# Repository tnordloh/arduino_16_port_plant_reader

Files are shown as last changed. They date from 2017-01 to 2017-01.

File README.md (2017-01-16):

# Plant moisture sensor, with up to 16 ports #

This moisture sensor uses arduino's analog sensor, to detect when a plant needs
to be watered.  Placing two wires into the plant soil, then sending a charge
through the soil will produce a number between 0 and 1023.  With some
experimentation, we picked "550" as dry, and "650" as REALLY dry.  

The Arduino we're using has only 6 analog ports, so we are extending the 
capabilities, by using two 
[SparkFun Analog/Digital MUX Breakout - CD74HC4067](https://www.sparkfun.com/products/9056).

the MUX (aka multiplexer) uses five ports, but can create access to 16 additional
ports.  We use two of these; one to apply power, the other to read how much 
power gets through.  

Additionally, each of the moisture sensors has an LED built into it, so that we
can light up  which of the 16 plants require watering.  To address the 16 lights, 
we are using two
[SN74HC595 8-Bit shift registers](https://www.sparkfun.com/products/13699), 
which consumes three more ports on the Arduino.

Since we had a couple of ports left over, we wired up a small lcd screen, so that
we can visually verify what each plant is actually registering.  This was 
just for fun, but it could be used to set each individual plant to its own
level of dryness, to make up for differences between each sensor, or differences
in soil, that might make the moisture sensors inaccurate.

Here's what the wiring diagram looks like:
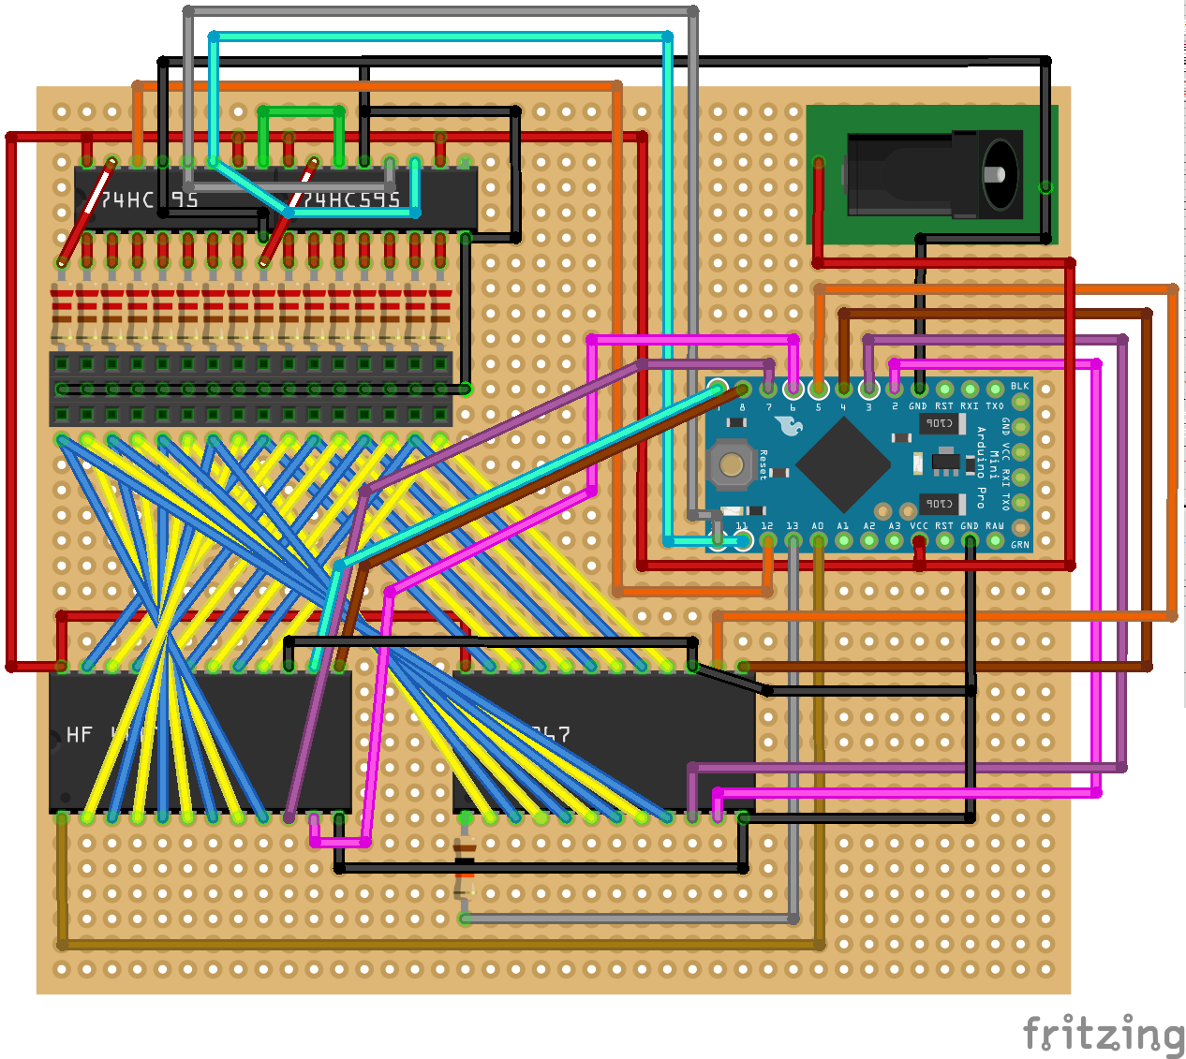
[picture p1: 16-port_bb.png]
fritzing file


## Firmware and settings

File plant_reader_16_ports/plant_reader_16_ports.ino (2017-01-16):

#include <SoftwareSerial.h>

int secondcount = 0;

// Attach the serial display's RX line to digital pin 2
SoftwareSerial mySerialData(A4,13); // RX,TX (unused)

int sensorValue[16] = {0,0,0,0,
                       0,0,0,0,
                       0,0,0,0,
                       0,0,0,0
                     };
int sensorpower = A0;

//Mux control pins
int s0 = 2;
int s1 = 3;
int s2 = 4;
int s3 = 5;

int s4 = 6;
int s5 = 7;
int s6 = 8;
int s7 = 9;
//int muxstate = 6;
//Mux in "SIG" pin
int SIG_pin = A1;


//set up shift register pins
int SER_Pin   = 10; //pin 14 on the 75HC595
int RCLK_Pin  = 11; //pin 12 on the 75HC595
int SRCLK_Pin = 12; //pin 11 on the 75HC595

//Number of daisy-chained shift registers
#define number_of_74hc595s 2 

//do not touch
#define numOfRegisterPins number_of_74hc595s * 8
boolean registers[numOfRegisterPins];

void setup() {

  pinMode(SER_Pin, OUTPUT);
  pinMode(RCLK_Pin, OUTPUT);
  pinMode(SRCLK_Pin, OUTPUT);


  pinMode(SIG_pin, INPUT);
  pinMode(sensorpower, OUTPUT);
  digitalWrite(sensorpower, LOW);

  //set Mux initial values
  pinMode(s0, OUTPUT); 
  pinMode(s1, OUTPUT); 
  pinMode(s2, OUTPUT); 
  pinMode(s3, OUTPUT); 
  pinMode(s4, OUTPUT); 
  pinMode(s5, OUTPUT); 
  pinMode(s6, OUTPUT); 
  pinMode(s7, OUTPUT); 
  //pinMode(muxstate, OUTPUT);

  //initialize mux to C0
  digitalWrite(s0, LOW);
  digitalWrite(s1, LOW);
  digitalWrite(s2, LOW);
  digitalWrite(s3, LOW);
  digitalWrite(s4, LOW);
  digitalWrite(s5, LOW);
  digitalWrite(s6, LOW);
  digitalWrite(s7, LOW);

  //start mux in "off" staate
  //digitalWrite(muxstate, LOW);
  mySerialData.begin(9600); // set up serial port for 9600 baud
  mySerialData.write(0x12);
  mySerialData.write("2");
  delay(500); // wait for display to boot up



  //Serial.begin(9600); 
  delay(500);

}

void loop() {

  secondcount++;
  if(secondcount % 6 == 0 ) {
    for(int x=0;x<16;++x) {
      checkSensors(x);
    }
  }
  for(int x=0;x<16;++x) {
    setLights(x);
  }
  writeRegisters();
  lcdStatus();
  delay(500);  
}

//set all register pins to LOW
void clearRegisters(){
  for(int i = numOfRegisterPins - 1; i >=  0; i--){
    registers[i] = LOW;
  }
}
/**************************************************************
 * Begin register-specific code
 *************************************************************/
//Set and display registers
//Only call AFTER all values are set how you would like (slow otherwise)
void writeRegisters(){

  digitalWrite(RCLK_Pin, LOW);

  for(int i = numOfRegisterPins - 1; i >=  0; i--){
    digitalWrite(SRCLK_Pin, LOW);
    //Serial.print(registers[i]);
    int val = registers[i];

    digitalWrite(SER_Pin, val);
    digitalWrite(SRCLK_Pin, HIGH);

  }
  //Serial.println();
  digitalWrite(RCLK_Pin, HIGH);

}

//set an individual pin HIGH or LOW
void setRegisterPin(int index, int value){
  registers[index] = value;
}

/*****************************************************
 * end register-specific functions
 **************************************************/
/**************************************************
 * begin mux-specific functions
 **************************************************/


int readSensor(int channel){
  //digitalWrite(muxstate,LOW);
  int controlPin[] = { s0, s1, s2, s3 };

  int muxChannel[16][4]={
    { 0,0,0,0 }, //channel 0
    { 1,0,0,0 }, //channel 1
    { 0,1,0,0 }, //channel 2
    { 1,1,0,0 }, //channel 3
    { 0,0,1,0 }, //channel 4
    { 1,0,1,0 }, //channel 5
    { 0,1,1,0 }, //channel 6
    { 1,1,1,0 }, //channel 7
    { 0,0,0,1 }, //channel 8
    { 1,0,0,1 }, //channel 9
    { 0,1,0,1 }, //channel 10
    { 1,1,0,1 }, //channel 11
    { 0,0,1,1 }, //channel 12
    { 1,0,1,1 }, //channel 13
    { 0,1,1,1 }, //channel 14
    { 1,1,1,1 }  //channel 15
  };

  //loop through the 4 sig
  for(int i = 0; i < 4; i ++){
    Serial.print("control pin:");
    Serial.print(i);
    Serial.print(" muxchannel:");
    Serial.println(muxChannel[channel][i]);
    digitalWrite(controlPin[i], muxChannel[channel][i]);
  }
  //return the value at the SIG pin
  return analogRead(SIG_pin);
}


void EnableSensor(int channel){
  //digitalWrite(muxstate,LOW);
  int controlPin[] = { s4, s5, s6, s7 };

  int muxChannel[16][4]={
    { 0,0,0,0 }, //channel 0
    { 1,0,0,0 }, //channel 1
    { 0,1,0,0 }, //channel 2
    { 1,1,0,0 }, //channel 3
    { 0,0,1,0 }, //channel 4
    { 1,0,1,0 }, //channel 5
    { 0,1,1,0 }, //channel 6
    { 1,1,1,0 }, //channel 7
    { 0,0,0,1 }, //channel 8
    { 1,0,0,1 }, //channel 9
    { 0,1,0,1 }, //channel 10
    { 1,1,0,1 }, //channel 11
    { 0,0,1,1 }, //channel 12
    { 1,0,1,1 }, //channel 13
    { 0,1,1,1 }, //channel 14
    { 1,1,1,1 }  //channel 15
  };

  //loop through the 4 sig
  for(int i = 0; i < 4; i ++){
    //Serial.print("control pin:");
    //Serial.print(i);
    //Serial.print(" muxchannel:");
    //Serial.println(muxChannel[channel][i]);
    digitalWrite(controlPin[i], muxChannel[channel][i]);
  }
  //read the value at the SIG pin
  //int val = analogRead(SIG_pin);
  //digitalWrite(muxstate,HIGH);
  //return the value
  //return val;
}

/**************************************************
 * end mux-specific functions
 **************************************************/

void checkSensors(int value) {
  //Serial.print("value:");
  //Serial.println(value);
  EnableSensor(value);
  digitalWrite(sensorpower,HIGH);
  //give power 10 ms to stabilize
  delay(10);
  //change to the correct sensor, then delay another 10 ms
  readSensor(value);
  delay(10);
  //do a final read
  sensorValue[value] = readSensor(value);
  //Serial.println(sensorValue[value]);  
  digitalWrite(sensorpower,LOW);
}

void setLights(int light) {
  if((secondcount % 4 == 0 || secondcount % 4 == 2)  && sensorValue[light] >650) {
    //digitalWrite(ledPin[light], HIGH);
    setRegisterPin(light, HIGH);
    //Serial.println("Light should be on (second is even, value >800");
  } 
  else if((secondcount % 4 == 1 || secondcount % 4 == 3)  && sensorValue[light] >650) {
    //Serial.println("Light should be off (second is odd, value >800");
    setRegisterPin(light, LOW);
    //digitalWrite(ledPin[light], LOW);
  } 
  else if(secondcount % 4 == 0 && sensorValue[light] >550) {
    //digitalWrite(ledPin[light], HIGH);
    setRegisterPin(light, HIGH);
    //Serial.println("Light should be on");
  } 
  else if(secondcount % 4 == 2 && sensorValue[light] >550) {
    setRegisterPin(light, LOW);
  } 
  else {
    setRegisterPin(light, LOW);
    //Serial.println("Light should be off");
  }

}
void lcdStatus() {
  int offset=secondcount%8/2*4;
  if(secondcount %1 == 0) {
    mySerialData.write(254); // move cursor to beginning of first line
    mySerialData.write(128);

    mySerialData.write("                "); // clear display
    mySerialData.write("                ");

    mySerialData.write(254); // move cursor to beginning of first line
    mySerialData.write(128);

    for(int i = 0;i<4;++i) {
      if(i == 2) {
        mySerialData.write(254); // move cursor to beginning of first line
        mySerialData.write(192);
      }      
      mySerialData.print(i+offset);
      mySerialData.print(":");

      mySerialData.print(sensorValue[i+offset]);
      mySerialData.print(" ");
    }
  }
}
